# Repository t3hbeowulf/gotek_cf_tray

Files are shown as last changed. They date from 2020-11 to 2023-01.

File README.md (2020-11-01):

# GoTek 5.25" Bay with CompactFlash slot
This is an OpenSCAD render of a custom 5.25" drive tray which holds a CompactFlash Adapter and the Gotek Floppy Emulator board. The intention was to take full advantage of FlashFloppy's enhancements to the Gotek Floppy Emulator (specifically, a rotary encoder for selection and OLED screen for information) and make a CF adpater accessible for easy removal on my RetroPC project.

### Features
- A slot for inserting and removing CF Cards from an ACS brand CF-to-IDE flash adapter
- A spot to mount a FlashFloppy enhanced Gotek Floppy Emulator
- A window sized for 0.96" OLED screen that connects to a FlashFloppy enhanced Gotek Floppy Emulator
- A rotary encoder for connecting to a FlashFloppy enhanced Gotek Floppy Emulator

### Tools used to render
- Cura Slicer v4.7.1+
- OpenSCAD v2019.5+

### Parts
- Gotek Floppy Emulator - https://www.amazon.com/gp/product/B0762NCHC6
- 0.96" Dual color OLED display - https://www.amazon.com/gp/product/B072Q2X2LL
- Rotary encoder - https://www.amazon.com/gp/product/B07DM2YMT4
- ACS-CF-IDEToCFA - http://www.acscontrol.com/pdf/Products/CF/IDEtoCF/Acs-CF-IDEToCFA.pdf
- 3D Printer of your choice

### Software to update a Gotek floppy emulator
- FlashFloppy Gotek Firmware - https://github.com/keirf/FlashFloppy
- HxCFloppyEmulator software - https://hxc2001.com/download/floppy_drive_emulator/index.html#stm32hxc

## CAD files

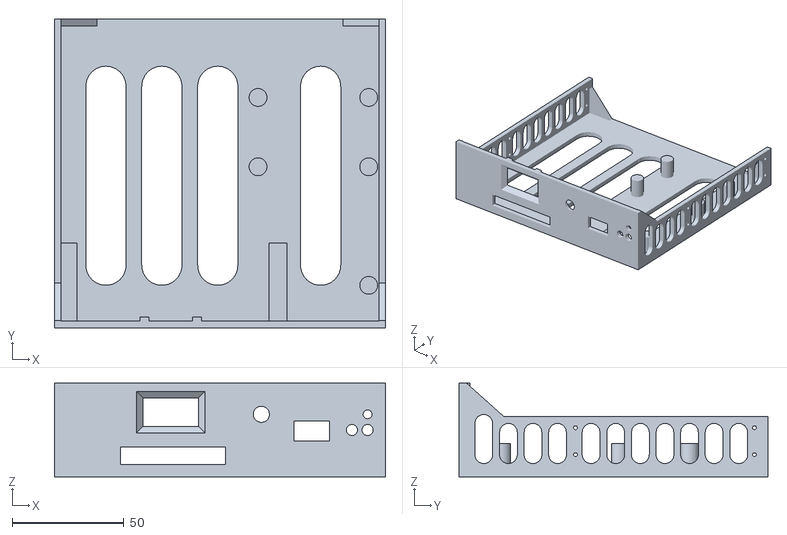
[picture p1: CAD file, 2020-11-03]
gotek_cf_tray_v1.4.stl
148.0 x 138.0 x 42.0

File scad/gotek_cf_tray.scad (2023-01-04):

// Gotek Floppy Emulator - 5.25" bay
// Written by Michael Berry <michaelaberry@gmail.com> and Joe Legeckis <thejml@gmail.com>
model_version = "v1.7.4";

// Features: 
//  - CF / IDE Card mount
//  - 1.2" OLED Display
//  - Gotek Floppy emulator ports
//  - Rotary Encoder

//Overall Drive size
// Z - 42mm (42.3mm max)
// X - 148mm (148.7mm max)
// Y - 138mm (flexible, min 136mm)

/* 
TODO:
Gotek: 
  back to middle: 21mm middle to front: 50mm pegs: 2.75mm 
  peg spread: 50mm
  front peg to front panel: 17mm

Rotary Encoder
- move indexing cutout to a flushmount cylinder on the inside wall. (too much stem outside)
- consider recessing the nut by 1mm to better flush the skirt of the knob

CF Adapter

- print support tabs with pins. (flexible mounting with/without screws)

OLED
- build a frame with captive side-walls and plastic pins
- frame may be connected at the top with room for data pins

*/

screw_insert_diameter = 3.2;

tray_x_front = 149;
tray_x = 146;
tray_y = 138;
tray_z = 42;

offset_tray_x_front = tray_x_front / 2;
offset_tray_x = tray_x / 2;
offset_tray_y = tray_y / 2;
offset_tray_z = tray_z / 2;

front_thickness = 3;

cf_adapter_location = [3 - offset_tray_x, front_thickness - offset_tray_y, offset_tray_z - 39];

//Render the main tray
module tray() {
    difference() {
        union() {
            translate([0,-offset_tray_y+front_thickness/2,0]) {
                color([1, 0.9, 0.9]) cube([tray_x_front, front_thickness, tray_z], center = true);
            }
            color([0.9, 0.9, 0.9]) cube([tray_x, tray_y, tray_z], center = true);
        }
        union() {
            // Carve out the inner tray
            translate([0, 3, 3]) {
                cube([tray_x - 6, tray_y, tray_z], center = true);
            }
        }
    }
}
 
difference() {
    union() {
        tray(); 
 
        // Support the sides on the back.
        backSupport();
        mirror([tray_x, 0, 0]) backSupport();
    
        // Rotary Encoder
        translate([offset_tray_x/4, offset_tray_y - tray_y, 28 - offset_tray_z]) {
            rotaryEncoderSupport(front_thickness,false);
        }

        // Support for CF, Gotek, LCD, and CF
        gotekBoardSupport(false);
        lcdSupports(false);
        cfBoardSupport(cf_adapter_location,false); 
    }
    union() {
        // Carve out the mounting holes
        trayMount();
        mirror([tray_x, 0, 0]) trayMount();

        translate([offset_tray_x / 4, offset_tray_y - tray_y, 28 - offset_tray_z]) {
            rotaryEncoderSupport(front_thickness,true);
        }

        // Save some plastic!
        plasticSaverSides();
        mirror([tray_x, 0, 0]) plasticSaverSides();
        plasticSaverBase();
        cfBoardSupport(cf_adapter_location, true);
        gotekBoardSupport(true);
        lcdSupports(true);

    }
}

echo("Model Version", model_version);

//Supports / Brackets / Mounts "Library"
module lcdSupports(do_deletes) {
    lcd_x = 27.5;
    lcd_y = 3;
    lcd_z = 28;

    mount_x = 4.1;
    mount_y = 1.75;
    mount_z = 3.5;
    thickness = 5;
    support_diameter = 3;

    bottom_to_display     = 9.8;
    overall_display_width = 28;
    overall_display_height= 28;

    // Screw holes x = 23.4mm
    // Screw holes z = 24mm
    // Screw Sizes = 2mm
    // https://www.amazon.com/gp/product/B09JWN8K99/ref=ewc_pr_img_1?smid=A1JX4L5CBS4J9K&th=1
    if (do_deletes==false) {
        color([0.8,0.4,0]) {
            translate([offset_tray_x-tray_x+37, offset_tray_y - tray_y + front_thickness+thickness, -7]) {
                translate([0,0,0]) cube([overall_display_width,2,bottom_to_display],center = false); 
                translate([overall_display_width,0-(thickness),0]) cube([2,thickness+2,bottom_to_display],center = false); 
                translate([-2,0-(thickness),0]) cube([2,thickness+2,bottom_to_display],center = false); 
                translate([-2,0-(thickness),-0.6]) cube([overall_display_width+4,thickness+2,0.6],center = false); 
            }
        }
    }
    if (do_deletes==true) {
        //LCD
        translate([51 - offset_tray_x + 6, offset_tray_y - tray_y - 0.5, 29 - offset_tray_z]) {
            //cube([26, 6, 14], center = true);
            //Screen size 14mm tall, 26mm wide (Scale opening to account for bezel)
            rotate([90, 0, 180]) trapezoidalPyramid(19.5, 31.5, 4);
        }
    } 
}

module cfBoardSupport(location, do_deletes) {
    /*  7mm to front
        24mm front to back support width
        93mm side to side support width
        2.5mm pegs
        CF Width: 48 
        Board right side to CF: 23 
        peg center to side: 3
    */
    support_width = 8;
    support_height = 2;
    cf_space = 2;
    cf_width = 43;
    cf_height = 4;
    cf_depth = 36.5;
    // Overall Placement
    translate(location) {
        color([0.8,0.65,0.5]) {
            if (do_deletes==false) {
                union() {
                    // Fake CF is 3mm up from botom of board... for Uncomment for Testing:
                    // CF is 43mm wide, sticks past the front of the PCB by 15mm out of 36.5mm deep and 3mm thick
                    // It's up 3mm from the bottom of the PCB. 
                    // Left to right, the CF starts at 28mm to 71mm out of 99mm PCB Width
                    translate([0,0,0]) {
                        cube([support_width, 35, support_height], center = false);
                    }

                    translate([93, 0, 0]) {
                        cube([support_width, 35, support_height], center = false);
                    }
                }
            } else {
                union() {
                    translate([  0+support_width/2,  7, -1]) cylinder(d = screw_insert_diameter, h = 3.5, $fn=36, center = false);
                    translate([ 93+support_width/2,  7, -1]) cylinder(d = screw_insert_diameter, h = 3.5, $fn=36, center = false);
                    translate([  0+support_width/2, 31, -1]) cylinder(d = screw_insert_diameter, h = 3.5, $fn=36, center = false);
                    translate([ 93+support_width/2, 31, -1]) cylinder(d = screw_insert_diameter, h = 3.5, $fn=36, center = false);

                    //CF Slot
                    translate([28-cf_space,-6,3+support_height-cf_space]) {
                        cube([cf_width+cf_space*2, 6.5+front_thickness, cf_height+cf_space*2], center = false);
                    }
                }
            } 
        }
    }
}

module gotekBoardSupport(do_deletes) {
    support_diameter = 8;
    support_height = 11.5;
    location = [offset_tray_x-7.5,21-offset_tray_y,offset_tray_z-tray_z+3];

    translate(location) {
        if (do_deletes==false) {
            color([0.0,0.7,1]) {
                difference() {
                    union() {
                        translate([-55,-8+front_thickness,0]) {
                            cube([60,88,support_height], center=false);
                        }
                        rotate([0,0,180]) translate([45,-100-front_thickness,0]) prism(10,20,support_height);
                        rotate([0,0,180]) translate([-5,-100-front_thickness,0]) prism(10,20,support_height);
                    }
                    union() {
                        translate([-45,-10+front_thickness,-1]) {
                            cube([40,100,support_height+2], center=false);
                        }
                        translate([-65,-17+front_thickness,-1]) {
                            cube([60,60,support_height+2], center=false);
                        }
                    }
                }
            } //color
        } else {
            //USB Port (15mm x 8mm)  [offset_tray_x_front - 41, offset_tray_y - tray_y, 16 - offset_tray_z]
            // USB Port 
            translate([-32.2, -22.5, support_height+2]) {
                color([1,0,0]) cube([15, 11, 9], center = false);
            }

            //Buttons (3mm diameter) XXX Fix These Locations Then re-enable the 'else'
            translate([   0,  -10.5, support_height+5]) {
                rotate([90, 0, 0]) cylinder(r = 2.5, h = 12, center = false, $fn = 15);
            }
            translate([  -8,  -10.5, support_height+5]) {
                rotate([90, 0, 0]) cylinder(r = 2.5, h = 12, center = false, $fn = 15);
            }
            // LED
            translate([   -0,  -10.5, support_height+12]) {
                rotate([90, 0, 0]) cylinder(r = 2, h = 12, center = false, , $fn = 15);
            }
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

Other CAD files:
gotek_cf_tray_v1.3.stl
gotek_cf_tray_v1.2.stl
gotek_cf_tray.stl

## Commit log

2020-11-01 Add STL drafts and current SCAD version
    [gotek_cf_tray.scad, gotek_cf_tray.stl, gotek_cf_tray_v1.2.stl]
2020-11-02 Add LCD supports, small fitment tweaks for front panel
    Move Gotek board inward by ~0.5mm, increase rotary encoder index hole size by ~0.625mm
    [gotek_cf_tray.scad]
2020-11-02 Add version to scad, render v1.3 to STL
    [gotek_cf_tray.scad, gotek_cf_tray_v1.3.stl]
2020-11-03 Code formatting, minor tweaks to LCD mounts
    [gotek_cf_tray.scad, gotek_cf_tray_v1.4.stl]
2020-11-10 Notes for improvements...
    [gotek_cf_tray.scad]
2022-11-28 v1.5: LCD Kanga-Mount, Rotary Encoder, Gotek and CF Support Updates
    [gotek_cf_tray.scad]
2022-12-15 Changing pillars to better supported rectangles and tweaks
    [gotek_cf_tray.scad]
2022-12-20 v1.7.3 - Fixing gotek sup height, rot encoder & space for IDE
    [gotek_cf_tray.scad]
2022-12-20 v1.7.4 - Using true/false instead of 1/0
    [gotek_cf_tray.scad]
